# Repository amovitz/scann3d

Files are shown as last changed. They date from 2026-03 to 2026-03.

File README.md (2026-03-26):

# scann3d

Real-time 3D object scanner using the VL53L8CX multi-zone time-of-flight sensor with dual LSM6DSVTR‎ IMU position tracking.

## Features

- **64-zone 3D visualization** - See the VL53L8CX's 8x8 measurement grid as rays in 3D space
- **Real-time IMU tracking** - Each LSM6DSVTR‎ gives independent real-time positioning
- **Temporal filtering** - Exponential moving average smooths noisy measurements
- **Plane fitting** - Least squares and RANSAC methods for surface detection
- **Mapping mode** - Accumulate points over time to build a 3D map of your environment

## Hardware

**Components (~$34/board, porotype cost as of 2026-03-18):**

- ESP32-C3-WROOM-02-N4‎ (~$3)
- VL53L8CX ToF sensor (~$7)
- 2x LSM6DSVTR‎ IMU (~$3)

All sensors share the I2C bus (same SDA/SCL pins).

### v1

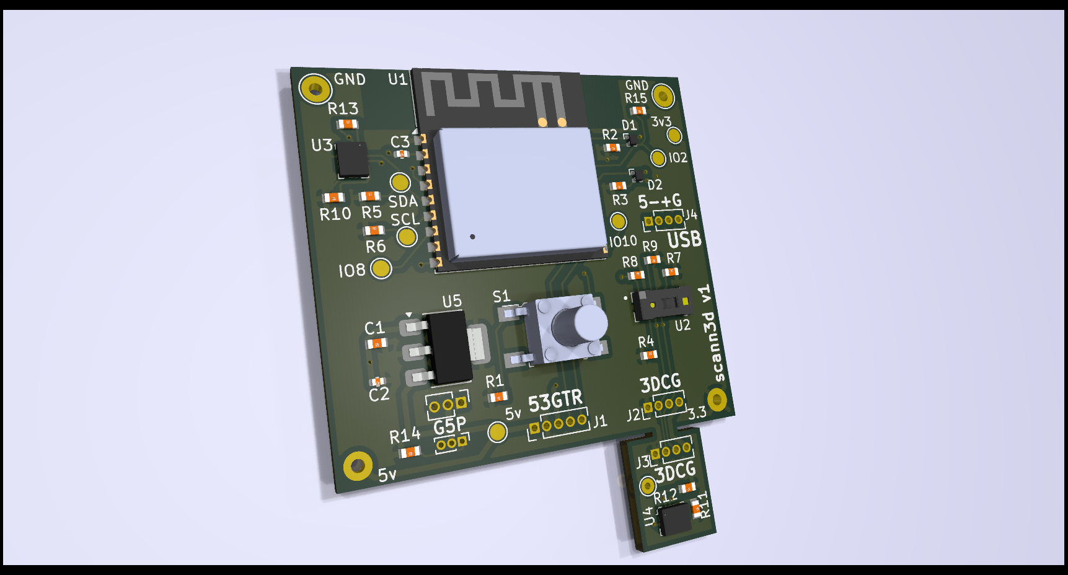
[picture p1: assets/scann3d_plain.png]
scann3d v1 board rendered with components


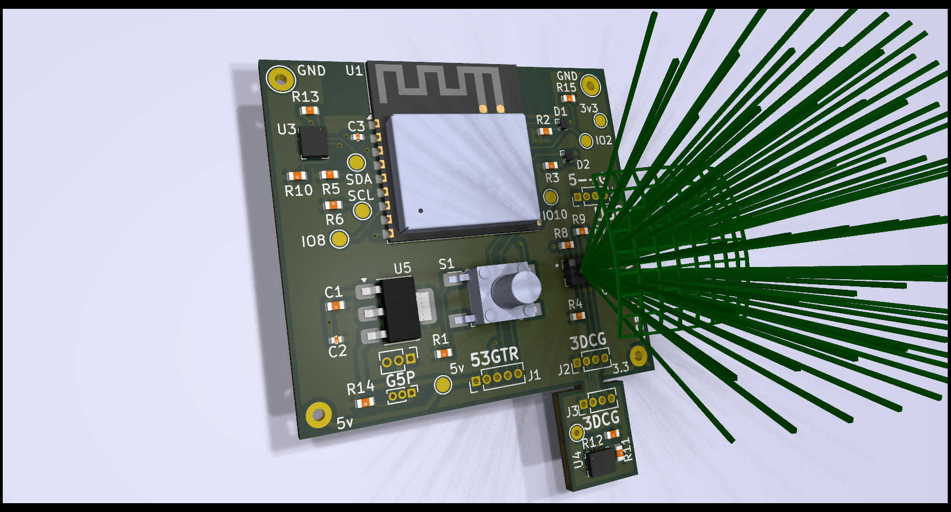
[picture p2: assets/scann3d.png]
scann3d v1 board rendered with components, also showing rendered distance field rays


Note: Distance scanning plane here appears curved, however distance reported by the VL53L8CX is perpendicular, not radial.

## Installation

### ESP32 Firmware

[Zephyr Firmware Instructions](zephyr-firmware/README.md)

### Python Viewer

**TODO:** Unbreak the integration with this Zephyr firmware...

```bash
pip install -r viewer/requirements.txt
```

## Usage

### ESP32 Board

| LED | Color | Behavior | Meaning |
|---|---|---|---|
| D1 | White | Blinking | Booting |
| D1 | Yellow | Blinking | WiFi connecting |
| D1 | Red | Blinking | WiFi disconnected |
| D1 | Green | Steady | WiFi connected |
| D1 | Green | Blinking | Output (USB serial+UDP) sending data |
| D1 | Off | Steady | Booted, actively scanning |
|---|---|---|---|
| D2 | White | Blinking | Booting |
| D2 | Cyan | Steady | Servo init failure |
| D2 | Magenta | Steady | UART0 init failure |
| D2 | Red | Steady | Output (USB serial+UDP) init failure |
| D2 | Green | Steady | ToF, IMU0 init success |
| D2 | Green | Blinking | ToF, IMU0, IMU1 init success |
| D2 | Yellow | Steady | ToF init success |
| D2 | Blue | Steady | IMU0 init success |
| D2 | Blue | Blinking | IMU0, IMU1 init success |
| D2 | Off | Steady | Booted, actively scanning |

Note: The LEDs will turn off after successfully booting and scanning begins. The ToF sensor works best in darkroom conditions.

### Python Viewer

```bash
python -m viewer --port /dev/ttyACM0
```

Open http://localhost:8080 in your browser.

**Options:**
- `--port`, `-p`: Serial port (default: `/dev/ttyACM0`)
- `--baud`, `-b`: Baud rate (default: `115200`)
- `--viser-port`: Viser server port (default: `8080`)
- `--debug`: Enable verbose logging

## Sensor Specs

**VL53L8CX** ([datasheet](https://www.st.com/resource/en/datasheet/vl53l8cx.pdf)):
- **FoV:** 65° diagonal (45° Hoizontal/Vertical)
- **Range:** 20mm - 4000mm
- **Distance type:** Perpendicular (z-axis), not radial

| Resolution | Zones | Max Frequency |
| --- | ----- | --- |
| 4x4 | 16 | 60 Hz |
| 8x8 | 64 | 15 Hz |

Currently configured for 8x8 at 15Hz.

---

## Forked from [ferrolho/VL53L5CX-BNO08X-viewer](https://github.com/ferrolho/VL53L5CX-BNO08X-viewer)

Watch the original video (https://youtu.be/s32OUzhjf4U)

## License

MIT

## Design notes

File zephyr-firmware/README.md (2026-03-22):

# scann3d

## Zephyr

| Library | Version |
|---|---|
| west | 1.5.0 |
| Zephyr | 4.3.0 |
| Tollchain | 0.17.3 |
| VL53L8CX ULD | 1.0.0 |

## Hardware - ESP32-C3-WROOM-02-N4

| Device | Part | Bus | Address | Notes |
|---|---|---|---|---|
| ToF sensor | VL53L8CX | I2C0 | 0x29 | I2C_RST - IO8 |
| Main IMU | LSM6DSV(TR) | I2C0 | 0x6A | On-Board |
| Tracker IMU | LSM6DSV(TR) | I2C1 | 0x6B | Detachable |

### Pin map (edit `boards/esp32c3_devkitc.overlay` to change)

```
IO0   LED1-B
IO1   LED1-G
IO2   LED1-R
IO3   LED2-B
IO4   LED2-G
IO5   LED2-R
IO6   I2C0 SDA
IO7   I2C0 SCL
IO8   VL53L8CX I2C_RST (active-low)
IO9   Servo PWM
IO10  RFU
IO18  USB D-  (native USB OTG - do not reassign)
IO19  USB D+  (native USB OTG - do not reassign)
IO20  RFU (Serial RXD)
IO21  RFU (Serial TXD)
```

Pull SA0 on the main LSM6DSV to GND -> address 0x6A.

Pull SA0 on the tracker LSM6DSV to VDD -> address 0x6B.

---

## Prerequisites

### Installing automatically 

I *highly* recommend installing the [Zephyr Extension for VSCode](https://marketplace.visualstudio.com/items?itemName=mylonics.zephyr-ide) and using it to install tools to the `zephyr-firmware` directory.

Once tools are installed, add a **Project** with the `esp32c3_devkitc` board.

Under **Project Config**, add the `boards/esp32c3_devkitc.overlay` to **zephyr-firmware/DTC Overlay**.

Then:

```bash
cd zephy-firmware
. .venv/bin/activate
west packages pip --install
west blobs fetch hal_espressif
```

### Installing manually

```bash
# Install west and the Zephyr SDK (>=0.16) first:
#   https://docs.zephyrproject.org/latest/develop/getting_started/index.html

pip install west

# Clone and initialise the workspace
cd zephy-firmware
west init
west update
west packages pip --install
west blobs fetch hal_espressif
west zephyr-export
```

### Building & Flashing manually

```bash
# Set your WiFi credentials (or edit prj.conf)
export SCANNER_WIFI_SSID="my_ap"
export SCANNER_WIFI_PSK="my_password"

west build -b esp32c3_devkitc ./ \
    -p \
    --build-dir build/esp32c3_devkitc \
    -- \
    -DCONFIG_SCANNER_WIFI_SSID=\"${SCANNER_WIFI_SSID}\" \
    -DCONFIG_SCANNER_WIFI_PSK=\"${SCANNER_WIFI_PSK}\"
    -DCONFIG_DEBUG_OPTIMIZATIONS=y \
    -DCONFIG_DEBUG_THREAD_INFO=y \
    -DEXTRA_DTC_OVERLAY_FILE='boards/esp32c3_devkitc.overlay;'

west flash
```

### VL53L8CX ULD (required - not bundled)

Download the driver from [ST Micro directly](https://www.st.com/en/embedded-software/stsw-img040.html).

[VL53L8CX ULD Reference Manual](https://www.st.com/resource/en/user_manual/um3109-a-guide-for-using-the-vl53l8cx-lowpower-highperformance-timeofflight-multizone-ranging-sensor-stmicroelectronics.pd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)

```bash
# Unzip files
unzip STSW-IMG040.zip

# Copy ULD API
cp STSW-IMG040/VL53L8CX_ULD_driver_2.0.1/VL53L8CX_ULD_API/src/* \
   STSW-IMG040/VL53L8CX_ULD_driver_2.0.1/VL53L8CX_ULD_API/inc/* \
   lib/vl53lcx_uld/

# Copy Platform
cp STSW-IMG040/VL53L8CX_ULD_driver_2.0.1/Platform/platform.c \
   STSW-IMG040/VL53L8CX_ULD_driver_2.0.1/Platform/platform.h \
   lib/vl53lcx_uld/
```

The ULD contains ST proprietary firmware; it cannot be redistributed here.

**Note:** Fix missing semicolon on line 368 of `vl53l8cx_api.c`

---

## Output streams

### USB serial (CDC-ACM)

Connect a USB cable. The device appears as `/dev/ttyACMx` (Linux) or
`COMx` (Windows). Baud rate is irrelevant - CDC-ACM is USB-native.

### UDP

Frames are sent to `CONFIG_SCANNER_UDP_HOST:CONFIG_SCANNER_UDP_PORT`
(default `192.168.1.100:5005`). The scanner holds a static IP
(`192.168.1.200`) by default; change `CONFIG_NET_CONFIG_MY_IPV4_ADDR`
in `prj.conf` or enable `CONFIG_NET_DHCPV4` to use DHCP instead.

### Raw serial

RFU

---

## JSON Protocol

TODO: Fill this section

## Raw Wire protocol

All frames share a 9-byte envelope:

```
[0x55][0xAA]  magic        2 bytes
[type]        packet type  1 byte  (0x01=ToF, 0x02=IMU0, 0x03=IMU1, 0x04=SER0, 0xFF=Status)
[seq]         sequence     2 bytes LE - per-type rolling counter
[len]         payload len  2 bytes LE
[payload]     N bytes
[crc16]       CRC-16/CCITT 2 bytes LE  (over type+seq+len+payload)
```

### Packet sizes

| Type | Payload | Total frame |
|---|---|---|
| PKT_TOF (0x01) | 329 bytes | 338 bytes |
| PKT_IMU0/1 (0x02/03) | 20 bytes | 29 bytes |
| PKT_SER0 (0x04) | 72 bytes | 81 bytes |
| PKT_STATUS (0xFF) | 5 bytes | 14 bytes |

### ToF payload (`tof_payload_t`)

64 zones in row-major order (zone 0 = top-left when sensor label faces up).

```c
uint32_t timestamp_ms
uint16_t distance_mm[64]       // centre target distance
uint16_t sigma_mm[64]          // ranging sigma
uint8_t  status[64]            // ULD target_status (5 = valid)
uint8_t  nb_target_detected[64]
```

### IMU payload (`imu_payload_t`)

```c
uint32_t timestamp_ms
int16_t  accel_{x,y,z}         // ±16 g,    LSB = 0.488 mg
int16_t  gyro_{x,y,z}          // ±2000 dps, LSB = 0.061 dps
int16_t  temp_raw              // °C = (raw / 256.0) + 25.0
```

---

## Sampling rates

| Sensor | Timer period | Effective rate |
|---|---|---|
| LSM6DSV (both) | 1 ms | up to 1 kHz drain; ODR = 3840 Hz internally |
| VL53L8CX | 66 ms | ~15 Hz (8×8 mode) |

Increase `CONFIG_SCANNER_TOF_PERIOD_MS` to 34 ms (~29 Hz) cautiously -
VL53L8CX firmware overhead over I2C at 400 kHz can exceed that budget at 8×8.

---

## Hot-plug tracker IMU

The tracker IMU (IMU1) is checked for presence every ~1024 IMU ticks (≈1 s).
If the connector is removed, `PKT_IMU1` frames simply stop. Re-inserting
the connector will resume frames within ~1 s without a reboot.

---

## Python receiver example

```python
import socket, struct, sys

MAGIC  = b'\x55\xAA'
HDR    = 7   # magic(2)+type(1)+seq(2)+len(2)
FTR    = 2   # crc16

sock = socket.socket(socket.AF_INET, socket.SOCK_DGRAM)
sock.bind(('0.0.0.0', 5005))

while True:
    data, addr = sock.recvfrom(4096)
    if data[:2] != MAGIC:
        continue
    pkt_type, seq, length = struct.unpack_from('<BHH', data, 2)
    payload = data[HDR:HDR+length]

    if pkt_type == 0x01:   # ToF
        ts, = struct.unpack_from('<I', payload, 0)
        dist = struct.unpack_from('<64H', payload, 4)
        print(f"[ToF  seq={seq}] ts={ts}ms  centre={dist[27]}mm")

    elif pkt_type in (0x02, 0x03):  # IMU
        ts, ax, ay, az, gx, gy, gz, tmp = struct.unpack_from('<IhhhhhHh', payload)
        label = 'IMU0' if pkt_type == 0x02 else 'IMU1'
        print(f"[{label} seq={seq}] ts={ts}ms  a=({ax},{ay},{az})  g=({gx},{gy},{gz})")
```

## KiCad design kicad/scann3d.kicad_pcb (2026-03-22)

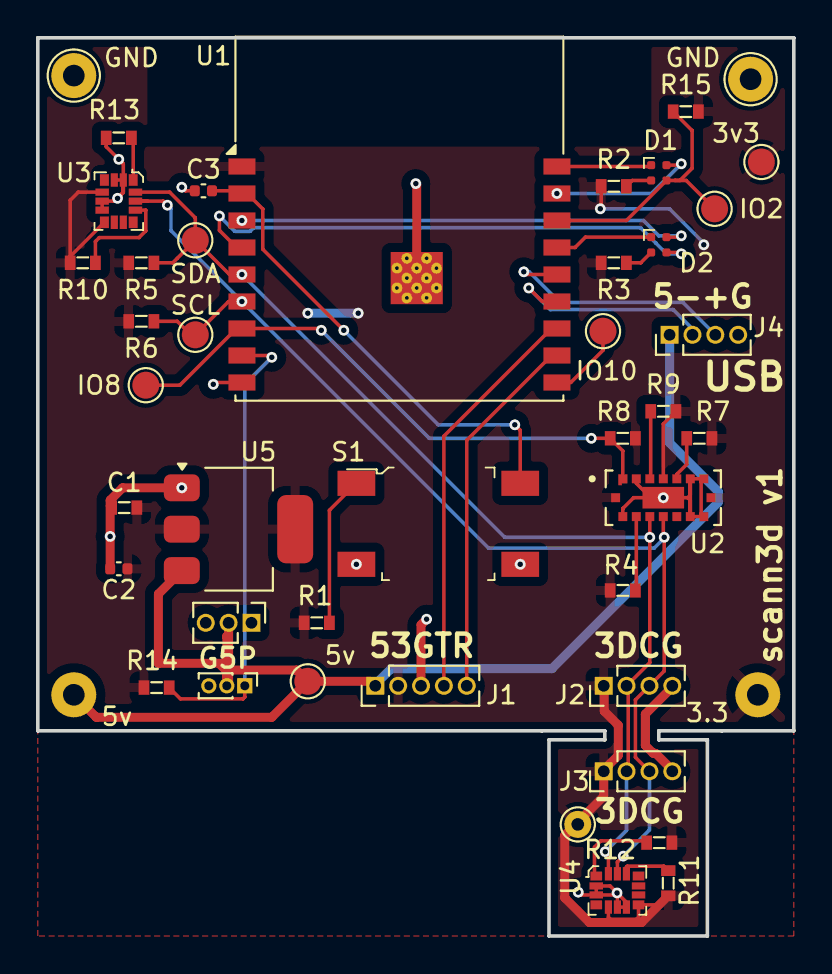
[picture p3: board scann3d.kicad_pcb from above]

Board: 2 copper layers, 42.0 x 49.9 mm, 40 parts (0 on the bottom side), 26 nets.

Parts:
3v3: LDO_Out; TestPoint_Pad_D1.5mm
5v: LDO_In; TestPoint_Pad_D1.5mm
C1: 100nf; 0603 (3D)
C2: 4.7uf; C_0402_1005Metric (3D)
C3: 100nf; C_0402_1005Metric (3D)
D1, D2: UHD111A-FKA; LED_Lumex_SML-LX0404SIUPGUSB
GND: TestPoint_THTPad_D2.5mm_Drill1.2mm
GND#2: TestPoint_THTPad_D2.5mm_Drill1.2mm
IO2: IO2; TestPoint_Pad_D1.5mm
IO8, IO10: LDO_In; TestPoint_Pad_D1.5mm
J1: Conn_01x05_Pin; PinHeader_1x05_P1.27mm_Vertical
J2, J3, J4: EXT_I2C; PinHeader_1x04_P1.27mm_Vertical
M1: 2589; PinHeader_1x03_P1.00mm_Vertical
R1, R14: 100k; 0603 (3D)
R2, R3, R15: 10k; 0603 (3D)
R4, R7, R8, R9, R10, R11, R12, R13: 47k; 0603 (3D)
R5, R6: 2.2k; 0603 (3D)
S1: 1825910-6; Switch_Tactile_SMD_6x6mm
SCL: SCL; TestPoint_Pad_D1.5mm
SDA: SDA; TestPoint_Pad_D1.5mm
U1: ESP32-C3-WROOM-02
U2: VL53L5CXV0GC_1; XDCR_VL53L5CXV0GC_1
U3, U4: LSM6DS3TR; LGA-14L_2.5x3mm__LSM6DS3
U5: LM3480-3.3; SOT-223-3_TabPin2

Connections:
+3.3V: 3v3.1, C1.1, C2.1, J1.2, J2.1, J3.1, R1.2, R2.2, R3.2, R4.1, R5.1, R6.1, R7.2, R8.2, R9.1, R10.2, R11.2, R12.1, R14.2, R15.1, U1.1 (3V3), U2.A4 (IOVDD), U2.B1 (AVDD), U2.B7 (AVDD__1), U3.5 (VDDIO), U3.8 (VDD), U4.5 (VDDIO), U4.8 (VDD), U5.2 (VO)
+5V: 5v.1, J1.1, J4.1, M1.2 (+), U5.3 (VI)
/I2C_RST: IO8.1, R8.1, U1.7 (IO8), U2.A1 (I2C_RST)
/PWM: M1.1 (PWM), R14.1, U1.8 (IO9)
/RXD: J1.5, U1.11 (IO20/RXD)
/SCL: J2.3, J3.3, R6.2, SCL.1, U1.6 (IO7), U2.C4 (SCL), U3.13 (SCL), U4.13 (SCL)
/SDA: J2.2, J3.2, R5.2, SDA.1, U1.5 (IO6), U2.C3 (SDA), U3.14 (SDA), U4.14 (SDA)
/TXD: J1.4, U1.12 (IO21/TXD)
GND: C1.2, C2.2, C3.2, GND.2, GND#2.1, J1.3, J2.4, J3.4, J4.4, M1.3 (-), R13.1, S1.3, S1.4, U1.9 (GND), U1.19 (GND), U2.A2 (RSVD4), U2.A6 (RSVD1), U2.A7 (RSVD2), U2.B4 (THERMALPAD), U2.C1 (GND), U2.C6 (RSVD3), U2.C7 (GND__1), U3.2 (SDx), U3.3 (SCx), U3.6 (GND), U3.7 (GND), U4.2 (SDx), U4.3 (SCx), U4.6 (GND), U4.7 (GND), U5.1 (GND)
unnamed: D1.4 (A), R2.1
unnamed: D1.1 (BK), U1.18 (IO0)
unnamed: D1.2 (GK), U1.17 (IO1)
unnamed: D1.3 (RK), IO2.1, R15.2, U1.16 (IO2)
unnamed: D2.4 (A), R3.1
unnamed: D2.1 (BK), U1.15 (IO3)
unnamed: D2.2 (GK), U1.3 (IO4)
unnamed: D2.3 (RK), U1.4 (IO5)
unnamed: R1.1, S1.1
unnamed: C3.1, S1.2, U1.2 (EN)
unnamed: R9.2, U2.A3 (INT)
unnamed: R7.1, U2.A5 (LPN)
unnamed: R4.2, U2.C2 (RSVD6)
unnamed: R10.1, U3.12 (CS)
unnamed: R13.2, U3.1 (SDO/SA0)
unnamed: R11.1, U4.12 (CS)
unnamed: R12.2, U4.1 (SDO/SA0)

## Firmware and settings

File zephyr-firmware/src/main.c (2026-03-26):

/*
 * main.c
 *
 * scann3d - ESP32-C3-WROOM-02-N4
 *
 * Boots peripherals in order, hands sensor contexts to the work subsystem,
 * then arms the sampling timers. All periodic work runs via k_timer ->
 * k_work -> system workqueue (see work_queues.c).
 *
 * Data flow:
 *   work handler -> proto_encode() -> data_output_push() -> output thread
 *                                                          ├─ udp_out_send()
 *                                                          └─ usb_serial_write()
 */

#include <zephyr/kernel.h>
#include <zephyr/logging/log.h>

#include "work_queues.h"
#include "protocol.h"
#include "vl53l8cx/vl53l8cx_driver.h"
#include "lsm6dsv/lsm6dsv_driver.h"
#include "output/data_output.h"
#include "led/led_ctrl.h"
#include "servo/servo_ctrl.h"
#include "uart_aux.h"
#include "wifi_mgr.h"

LOG_MODULE_REGISTER(main, LOG_LEVEL_INF);

int main(void)
{
    LOG_INF("=== scann3d booting ===");

    /* 1. LED controller - init first so we can signal status visually */
    if (led_ctrl_init() != 0) {
        LOG_ERR("LED init failed");
        /* Non-fatal - continue booting */
    }

    /* Boot indicator: both LEDs white, fast blink */
    led_set_blink(LED_D1, LED_COLOR_WHITE, 100);
    led_set_blink(LED_D2, LED_COLOR_WHITE, 100);

    /* 2. Servo controller */
    if (servo_ctrl_init() != 0) {
        LOG_ERR("Servo init failed");
        led_set_color(LED_D2, LED_COLOR_CYAN);     /* steady cyan = fatal */
    }

    /* 3. Auxiliary UART0 (IO20/IO21 - available for future use) */
    if (uart_aux_init() != 0) {
        LOG_WRN("Auxiliary UART init failed (non-fatal)");
        led_set_color(LED_D2, LED_COLOR_MAGENTA);  /* steady magenta = fatal */
    }

    /* 4. Output subsystem (USB serial + UDP socket) */
    if (data_output_init() != 0) {
        LOG_ERR("Output init failed - halting");
        led_set_color(LED_D2, LED_COLOR_RED);      /* steady red = fatal */
        return -1;
    }

    /* 5. WiFi - non-fatal; UDP won't work but USB-serial will */
    led_set_blink(LED_D1, LED_COLOR_YELLOW, 500);  /* yellow blink = connecting */
    if (wifi_mgr_connect() != 0) {
        LOG_WRN("WiFi unavailable - UDP output disabled");
        led_set_blink(LED_D1, LED_COLOR_RED, 500); /* blinking red = no WiFi */
    } else {
        led_set_color(LED_D1, LED_COLOR_GREEN);    /* steady green = WiFi up */
    }

    /* 6. Sensors */
    vl53l8cx_ctx_t *tof_ctx  = vl53l8cx_driver_init(CONFIG_SCANNER_TOF_PERIOD_MS);
    if (!tof_ctx) {
        LOG_ERR("VL53L8CX init failed");
    }

    lsm6dsv_ctx_t *imu0_ctx = lsm6dsv_init(IMU_MAIN);
    if (!imu0_ctx) {
        LOG_ERR("LSM6DSV main init failed");
    }

    lsm6dsv_ctx_t *imu1_ctx = lsm6dsv_init(IMU_TRACK);
    if (!imu1_ctx) {
        LOG_WRN("LSM6DSV tracker not present (detachable - OK)");
    }

    /* D2 indicates sensor readiness: green = ToF+IMU OK, yellow = ToF only, blue = IMU only */
    if (tof_ctx && imu0_ctx) {
        imu1_ctx ? led_set_blink(LED_D2, LED_COLOR_GREEN, 500)
                 : led_set_color(LED_D2, LED_COLOR_GREEN);
    } else if (tof_ctx) {
        led_set_color(LED_D2, LED_COLOR_YELLOW);
    } else if (imu0_ctx) {
        imu1_ctx ? led_set_blink(LED_D2, LED_COLOR_BLUE, 500)
                 : led_set_color(LED_D2, LED_COLOR_BLUE);
    }

    /* 7. Hand contexts to the work subsystem and start timers */
    work_queues_init(tof_ctx, imu0_ctx, imu1_ctx);
    work_queues_start(CONFIG_SCANNER_IMU_PERIOD_MS,
                      CONFIG_SCANNER_TOF_PERIOD_MS,
                      CONFIG_SCANNER_STATUS_PERIOD_MS);

    /* Wait a few seconds and turn off LEDs for darkroom conditions */
    k_sleep(K_SECONDS(3));
    led_set_color(LED_D1, LED_COLOR_OFF);
    led_set_color(LED_D2, LED_COLOR_OFF);

    /* Main thread has nothing left to do - everything runs via timers/work. */
    while (true) {
        k_sleep(K_FOREVER);
    }

    return 0;
}

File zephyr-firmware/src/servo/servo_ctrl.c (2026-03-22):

/*
 * servo_ctrl.c
 *
 * 360-degree servo controller using ESP32-C3 LEDC hardware PWM.
 *
 * The PWM hardware autonomously generates the 50 Hz signal once set.
 * The servo thread blocks on the message queue; when a new position arrives
 * it calls pwm_set_dt() and returns to blocking - no busy-waiting.
 *
 * Pulse-width calculation (all in nanoseconds):
 *
 *   period    = 20 000 000 ns  (20 ms)
 *   mid       =  1 500 000 ns  (1500 µs - stop)
 *   range     =    500 000 ns  (±500 µs either side of mid)
 *   pulse(p)  = mid + (int32_t)(p × range)
 *
 *   p = -1.0  ->  pulse = 1 000 000 ns  (1 ms, full CW)
 *   p =  0.0  ->  pulse = 1 500 000 ns  (1.5 ms, stopped)
 *   p = +1.0  ->  pulse = 2 000 000 ns  (2 ms, full CCW)
 *
 * DT node used:
 *   servo0_pwm  - defined in boards/esp32c3_devkitm.overlay
 *   ledc0 ch0   - IO9, 50 Hz, timer 0
 */

#include "servo_ctrl.h"

#include <zephyr/kernel.h>
#include <zephyr/drivers/pwm.h>
#include <zephyr/logging/log.h>
#include "protocol.h"
#include "data_output.h"

LOG_MODULE_REGISTER(servo_ctrl, LOG_LEVEL_INF);

/* ── PWM timing constants (nanoseconds) ──────────────────────────────────── */
#define SERVO_PERIOD_NS   20000000u   /* 20 ms  - 50 Hz                  */
#define SERVO_MID_NS       1500000u   /* 1500 µs - neutral / stopped      */
#define SERVO_RANGE_NS      500000u   /* ±500 µs - full travel either way */

/* ── DT PWM specs - one entry per servo ─────────────────────────────────── */
static const struct pwm_dt_spec servo_pwm[NUM_SERVOS] = {
    [SERVO_0] = PWM_DT_SPEC_GET(DT_NODELABEL(servo0_pwm)),
};

/* ── Message queue ────────────────────────────────────────────────────────── */
#define SERVO_QUEUE_DEPTH  8u
K_MSGQ_DEFINE(servo_msgq, sizeof(servo_msg_t), SERVO_QUEUE_DEPTH, 4);

/* ── Thread ───────────────────────────────────────────────────────────────── */
#define SERVO_THREAD_STACK  1024u
#define SERVO_THREAD_PRIO   8

static K_THREAD_STACK_DEFINE(servo_stack, SERVO_THREAD_STACK);
static struct k_thread servo_thread_data;

/**
 * Clamp a float to [lo, hi] without pulling in libm.
 * Using a conditional expression keeps it fully inline.
 */
static inline float fclamp(float v, float lo, float hi)
{
    return v < lo ? lo : (v > hi ? hi : v);
}

static void servo_thread_fn(void *p1, void *p2, void *p3)
{
    ARG_UNUSED(p1); ARG_UNUSED(p2); ARG_UNUSED(p3);

    servo_msg_t msg;
    static uint16_t seq_servo = 0;

    while (true) {
        /* Block indefinitely until a new command arrives */
        if (k_msgq_get(&servo_msgq, &msg, K_FOREVER) != 0) {
            continue;
        }

        if (msg.servo >= NUM_SERVOS) {
            LOG_WRN("servo_ctrl: invalid servo index %u", msg.servo);
            continue;
        }

        /* Map position [-1.0, +1.0] -> pulse width in nanoseconds */
        float pos = fclamp(msg.position, SERVO_POS_FULL_CW, SERVO_POS_FULL_CCW);
        uint32_t pulse_ns = (uint32_t)((int32_t)SERVO_MID_NS
                            + (int32_t)(pos * (float)SERVO_RANGE_NS));

        int rc = pwm_set_dt(&servo_pwm[msg.servo],
                            SERVO_PERIOD_NS, pulse_ns);
        if (rc != 0) {
            LOG_ERR("servo_ctrl: pwm_set_dt failed: %d", rc);
        } else {
            servo_payload_t payload = {
                .timestamp_ms = k_uptime_get_32(),
                .position     = msg.position,
                .servo_num    = msg.servo,
            };

            data_output_send(PKT_STATUS, seq_servo++, &payload, sizeof(payload));

            LOG_DBG("servo %u -> pos=%.3f pulse=%u ns",
                    msg.servo, (double)pos, pulse_ns);
        }
    }
}

/* ── Public API ───────────────────────────────────────────────────────────── */
int servo_ctrl_init(void)
{
    /* Verify PWM devices are ready */
    for (uint8_t i = 0u; i < NUM_SERVOS; i++) {
        if (!pwm_is_ready_dt(&servo_pwm[i])) {
            LOG_ERR("PWM device not ready for servo %u", i);
            return -ENODEV;
        }
        /* Park at neutral (stopped) */
        int rc = pwm_set_dt(&servo_pwm[i], SERVO_PERIOD_NS, SERVO_MID_NS);
        if (rc != 0) {
            LOG_ERR("servo_ctrl: init pwm_set_dt[%u] failed: %d", i, rc);
            return rc;
        }
    }

    /* Start consumer thread */
    k_thread_create(&servo_thread_data, servo_stack,
                    K_THREAD_STACK_SIZEOF(servo_stack),
                    servo_thread_fn, NULL, NULL, NULL,
                    SERVO_THREAD_PRIO, 0, K_NO_WAIT);
    k_thread_name_set(&servo_thread_data, "servo");

    LOG_INF("Servo controller ready (%u servo(s), IO9, 50 Hz)", NUM_SERVOS);
    return 0;
}

int servo_set_position(uint8_t servo, float position)
{
    if (servo >= NUM_SERVOS) {
        return -EINVAL;
    }
    servo_msg_t msg = {
        .servo    = servo,
        .position = position,
    };
    return k_msgq_put(&servo_msgq, &msg, K_NO_WAIT);
}

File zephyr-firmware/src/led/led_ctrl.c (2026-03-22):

/*
 * led_ctrl.c
 *
 * Time-division multiplexed RGB LED driver.
 *
 * Architecture
 * ─────────────
 *  led_mux_timer  - k_timer firing every MUX_PERIOD_US µs (~750 Hz).
 *                   Submits led_mux_work to the system workqueue.
 *
 *  led_mux_work   - Workqueue handler; does the real work:
 *                   1. Drain all pending messages from led_msgq.
 *                   2. For each LED, determine visibility (blink state).
 *                   3. Advance the mux slot and set the correct GPIO.
 *
 * GPIO indexing (per-LED channel array index -> colour bit):
 *   [0] = Red   [1] = Green   [2] = Blue
 *
 * colour_mask[] encodes which channels are active as a 3-bit field:
 *   bit 0 = Red,  bit 1 = Green,  bit 2 = Blue
 */

#include "led_ctrl.h"

#include <zephyr/kernel.h>
#include <zephyr/drivers/gpio.h>
#include <zephyr/logging/log.h>

LOG_MODULE_REGISTER(led_ctrl, LOG_LEVEL_INF);

/* ── Tuning ───────────────────────────────────────────────────────────────── */
#define MUX_PERIOD_US    1333u   /* ~750 Hz timer -> 250 Hz per channel in WHITE */
#define LED_QUEUE_DEPTH  8u

/* ── DT GPIO specs  [led_index][channel: 0=R 1=G 2=B] ────────────────────── */
static const struct gpio_dt_spec led_gpios[NUM_LEDS][3] = {
    [LED_D1] = {
        [0] = GPIO_DT_SPEC_GET(DT_NODELABEL(d1_r), gpios),
        [1] = GPIO_DT_SPEC_GET(DT_NODELABEL(d1_g), gpios),
        [2] = GPIO_DT_SPEC_GET(DT_NODELABEL(d1_b), gpios),
    },
    [LED_D2] = {
        [0] = GPIO_DT_SPEC_GET(DT_NODELABEL(d2_r), gpios),
        [1] = GPIO_DT_SPEC_GET(DT_NODELABEL(d2_g), gpios),
        [2] = GPIO_DT_SPEC_GET(DT_NODELABEL(d2_b), gpios),
    },
};

/* ── Colour -> active-channel bitmask ─────────────────────────────────────── */
#define CH_R  BIT(0)
#define CH_G  BIT(1)
#define CH_B  BIT(2)

static const uint8_t color_mask[_LED_COLOR_MAX] = {
    [LED_COLOR_OFF]     = 0,
    [LED_COLOR_RED]     = CH_R,
    [LED_COLOR_GREEN]   = CH_G,
    [LED_COLOR_BLUE]    = CH_B,
    [LED_COLOR_YELLOW]  = CH_R | CH_G,
    [LED_COLOR_CYAN]    = CH_G | CH_B,
    [LED_COLOR_MAGENTA] = CH_R | CH_B,
    [LED_COLOR_WHITE]   = CH_R | CH_G | CH_B,
};

/* ── Per-LED runtime state ────────────────────────────────────────────────── */
struct led_state {
    led_color_t color;
    uint8_t     mux_slot;      /* index into active channels list, 0-based */
    uint32_t    blink_ms;
};

static struct led_state led_state[NUM_LEDS];

/* ── Message queue ────────────────────────────────────────────────────────── */
K_MSGQ_DEFINE(led_msgq, sizeof(led_msg_t), LED_QUEUE_DEPTH, 4);

/* ── Helpers ──────────────────────────────────────────────────────────────── */

/** Return the index (0/1/2) of the n-th set bit in mask, or 0xFF if none. */
static uint8_t nth_set_bit(uint8_t mask, uint8_t n)
{
    for (uint8_t i = 0u; i < 3u; i++) {
        if (mask & BIT(i)) {
            if (n == 0u) {
                return i;
            }
            n--;
        }
    }
    return 0xFFu;
}

/** Count set bits in a 3-bit mask. */
static uint8_t popcount3(uint8_t mask)
{
    return (uint8_t)(__builtin_popcount(mask & 0x07u));
}

/** Turn off all three channels of one LED. */
static inline void led_all_off(uint8_t led)
{
    gpio_pin_set_dt(&led_gpios[led][0], 0);
    gpio_pin_set_dt(&led_gpios[led][1], 0);
    gpio_pin_set_dt(&led_gpios[led][2], 0);
}

/** Set exactly one channel of one LED on, the rest off. */
static inline void led_set_channel(uint8_t led, uint8_t ch)
{
    gpio_pin_set_dt(&led_gpios[led][0], ch == 0u ? 1 : 0);
    gpio_pin_set_dt(&led_gpios[led][1], ch == 1u ? 1 : 0);
    gpio_pin_set_dt(&led_gpios[led][2], ch == 2u ? 1 : 0);
}

/* ── Mux work handler ─────────────────────────────────────────────────────── */
static void led_mux_work_handler(struct k_work *w)
{
    ARG_UNUSED(w);

    /* 1. Drain all queued messages ─────────────────────────────────────────── */
    led_msg_t msg;
    while (k_msgq_get(&led_msgq, &msg, K_NO_WAIT) == 0) {
        if (msg.diode >= NUM_LEDS) {
            continue;
        }
        struct led_state *s = &led_state[msg.diode];

        if (msg.type == LED_MSG_COLOR) {
            if (msg.color < _LED_COLOR_MAX) {
                s->color    = msg.color;
                s->mux_slot = 0u;
                s->blink_ms = 0u;
            }
        } else {  /* LED_MSG_BLINK */
            s->blink_ms  = msg.blink_ms;
        }
    }

    /* 2. Update each LED ───────────────────────────────────────────────────── */
    int64_t now_ms = k_uptime_get();

    for (uint8_t led = 0u; led < NUM_LEDS; led++) {
        struct led_state *s = &led_state[led];

        /* ── Blink gating ──────────────────────────────────────────────────── */
        bool visible = true;
        if (s->blink_ms > 0u) {
            uint32_t cycle = s->blink_ms * 2;
            if (cycle > 0u) {
                uint32_t phase = (uint32_t)(now_ms % (int64_t)cycle);
                visible = (phase < s->blink_ms);
            }
        }

        /* ── Apply colour via mux ──────────────────────────────────────────── */
        uint8_t mask = color_mask[s->color];

        if (!visible || mask == 0u) {
            led_all_off(led);
            continue;
        }

        uint8_t nch = popcount3(mask);
        if (nch == 1u) {
            /* Pure colour - no muxing needed, hold the channel steady */
            led_set_channel(led, nth_set_bit(mask, 0u));
        } else {
            /* Mixed colour - advance slot and activate next channel */
            s->mux_slot = (uint8_t)((s->mux_slot + 1u) % nch);
            led_set_channel(led, nth_set_bit(mask, s->mux_slot));
        }
    }
}

static K_WORK_DEFINE(led_mux_work, led_mux_work_handler);

/* ── Mux timer callback (ISR context - just submits work) ─────────────────── */
static void led_mux_timer_cb(struct k_timer *t)
{
    ARG_UNUSED(t);
    k_work_submit(&led_mux_work);
}

static K_TIMER_DEFINE(led_mux_timer, led_mux_timer_cb, NULL);

/* ── Public API ───────────────────────────────────────────────────────────── */
int led_ctrl_init(void)
{
    /* Configure all LED GPIOs as outputs, initially LOW (off) */
    for (uint8_t led = 0u; led < NUM_LEDS; led++) {
        for (uint8_t ch = 0u; ch < 3u; ch++) {
            const struct gpio_dt_spec *g = &led_gpios[led][ch];
            if (!gpio_is_ready_dt(g)) {
                LOG_ERR("LED GPIO not ready: led=%u ch=%u", led, ch);
                return -ENODEV;
            }
            gpio_pin_configure_dt(g, GPIO_OUTPUT_INACTIVE);
        }
        led_state[led].color        = LED_COLOR_OFF;
        led_state[led].mux_slot     = 0u;
        led_state[led].blink_ms     = 0u;
    }

    /* Start mux timer */
    k_timer_start(&led_mux_timer,
                  K_USEC(MUX_PERIOD_US),
                  K_USEC(MUX_PERIOD_US));

    LOG_INF("LED controller started (mux @ ~%u Hz)",
            (unsigned)(1000000u / MUX_PERIOD_US));
    return 0;
}
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

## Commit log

2026-03-22 Adds scann3d v1 hardware.
    [scann3d-B_Cu.gbr, scann3d-B_Mask.gbr, scann3d-B_Paste.gbr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]
2026-03-22 Initial zephyr yolo commit.
    This zephyr project was templated by claude.ai (Sonnet 4.6, Extended)
    given the sensors and pinout. No shot it works lmao
    [pwm-servo.yaml]
2026-03-22 Fixes issues with VL53L8CX ULD.
    Adds instructions to download and set up VL53L8CX ULD drivers.
    [led_ctrl.h, main.c, servo_ctrl.h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]
2026-03-22 Cleans up LED control and documents indicator behavior.
2026-03-22 Prints more network info.
2026-03-22 Adds servo position reporting.
2026-03-26 Turns off LEDs when scanning has started.
